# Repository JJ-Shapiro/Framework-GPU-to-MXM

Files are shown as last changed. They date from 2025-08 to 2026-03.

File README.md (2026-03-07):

# Framework-GPU-to-MXM
A project to make the first MXM module for the Framework 16.
*Info*
The Framework 16's Expansion bay can't support the size of an MXM module by default, (at least not a type-B module which is bigger than a type a module), but it *can* support it if the back of the GPU expansion slot is pulled out further 

Screenshot 2026-01-25 at 11 29 57 pm



3D_PCB6_2025-08-20



*Disclaimer*
I am not the legal owner of the datasheet describing the footprint of an MXM connector. It is in this repository strictly as a helpful reference for anyone who might desire to use or cross reference it. I will of course remove it at the request of the author.

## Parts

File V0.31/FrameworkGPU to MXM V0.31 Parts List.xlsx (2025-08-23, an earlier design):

No. | Quantity | Comment | Designator | Footprint | Value | Manufacturer Part | Manufacturer | Supplier Part | Supplier | Input Voltage | Datasheet | Current Rating - Power (Max)
1 | 16 | 220nF | C1,C2,C3,C4,C5,C6,C7,C8,C9,C10,C11,C12,C13,C14,C15,C16 | C0402 | 220nF
2 | 11 | 100nF | C17,C18,C19,C20,C21,C22,C23,C24,C25,C26,C27 | C0603 | 100nF
3 | 3 | 0.1uF | C73,C74,C75 | C0402
4 | 2 | SFW4R-2STE1LF | FPC1,FPC2 | CONN-SMD_4P-P1.00_L5.5-W9.8 |  | SFW4R-2STE1LF | Amphenol | C464570 | LCSC |  | https://atta.szlcsc.com/upload/public/pdf/source/20191127/C464570_B2B1FDB2254A36EE71D2D8D3CD76F95C.pdf
5 | 1 | MXM3.0 | J1 | CONN-SMD_314P-P0.50_10151114-001TLF | MXM3.0
6 | 1 | 100M | L1 | L0603 | 100M
7 | 3 | 0/NC | R43,R45,R47 | R0402 | 0/NC
8 | 9 | 0 | R44,R46,R48,R53,R54,R55,R56,R59,R60 | R0402 | 0
9 | 2 | 100K ±1% | R49,R52 | R0402 | 100K ±1%
10 | 2 | 4.7K ±1% | R50,R51 | R0402 | 4.7K ±1%
11 | 2 | 330k ±1% | R57,R58 | R0402 | 330k ±1%
12 | 29 | Test-Point | TP1,TP2,TP3,TP4,TP5,TP6,TP7,TP8,TP9,TP10,TP11,TP12,TP13,TP14,TP15,TP16,TP17,TP18,TP19,TP20,TP21,TP22,TP23,TP24,TP25,TP26,TP27,TP28,TP29 | Test-Point-0.5mm
13 | 1 | FXBeam | U2 | FW_FXBEAM_FULL
14 | 1 | BR24G32FVT-3GE2 | U54 | TSSOP-8_L4.4-W3.0-P0.65-LS6.4-BL |  | BR24G32FVT-3GE2 | ROHM(罗姆) | C2061284 | LCSC |  | https://atta.szlcsc.com/upload/public/pdf/source/20211207/04F260C112D11C6089B8D1D4B01C0AA6.pdf

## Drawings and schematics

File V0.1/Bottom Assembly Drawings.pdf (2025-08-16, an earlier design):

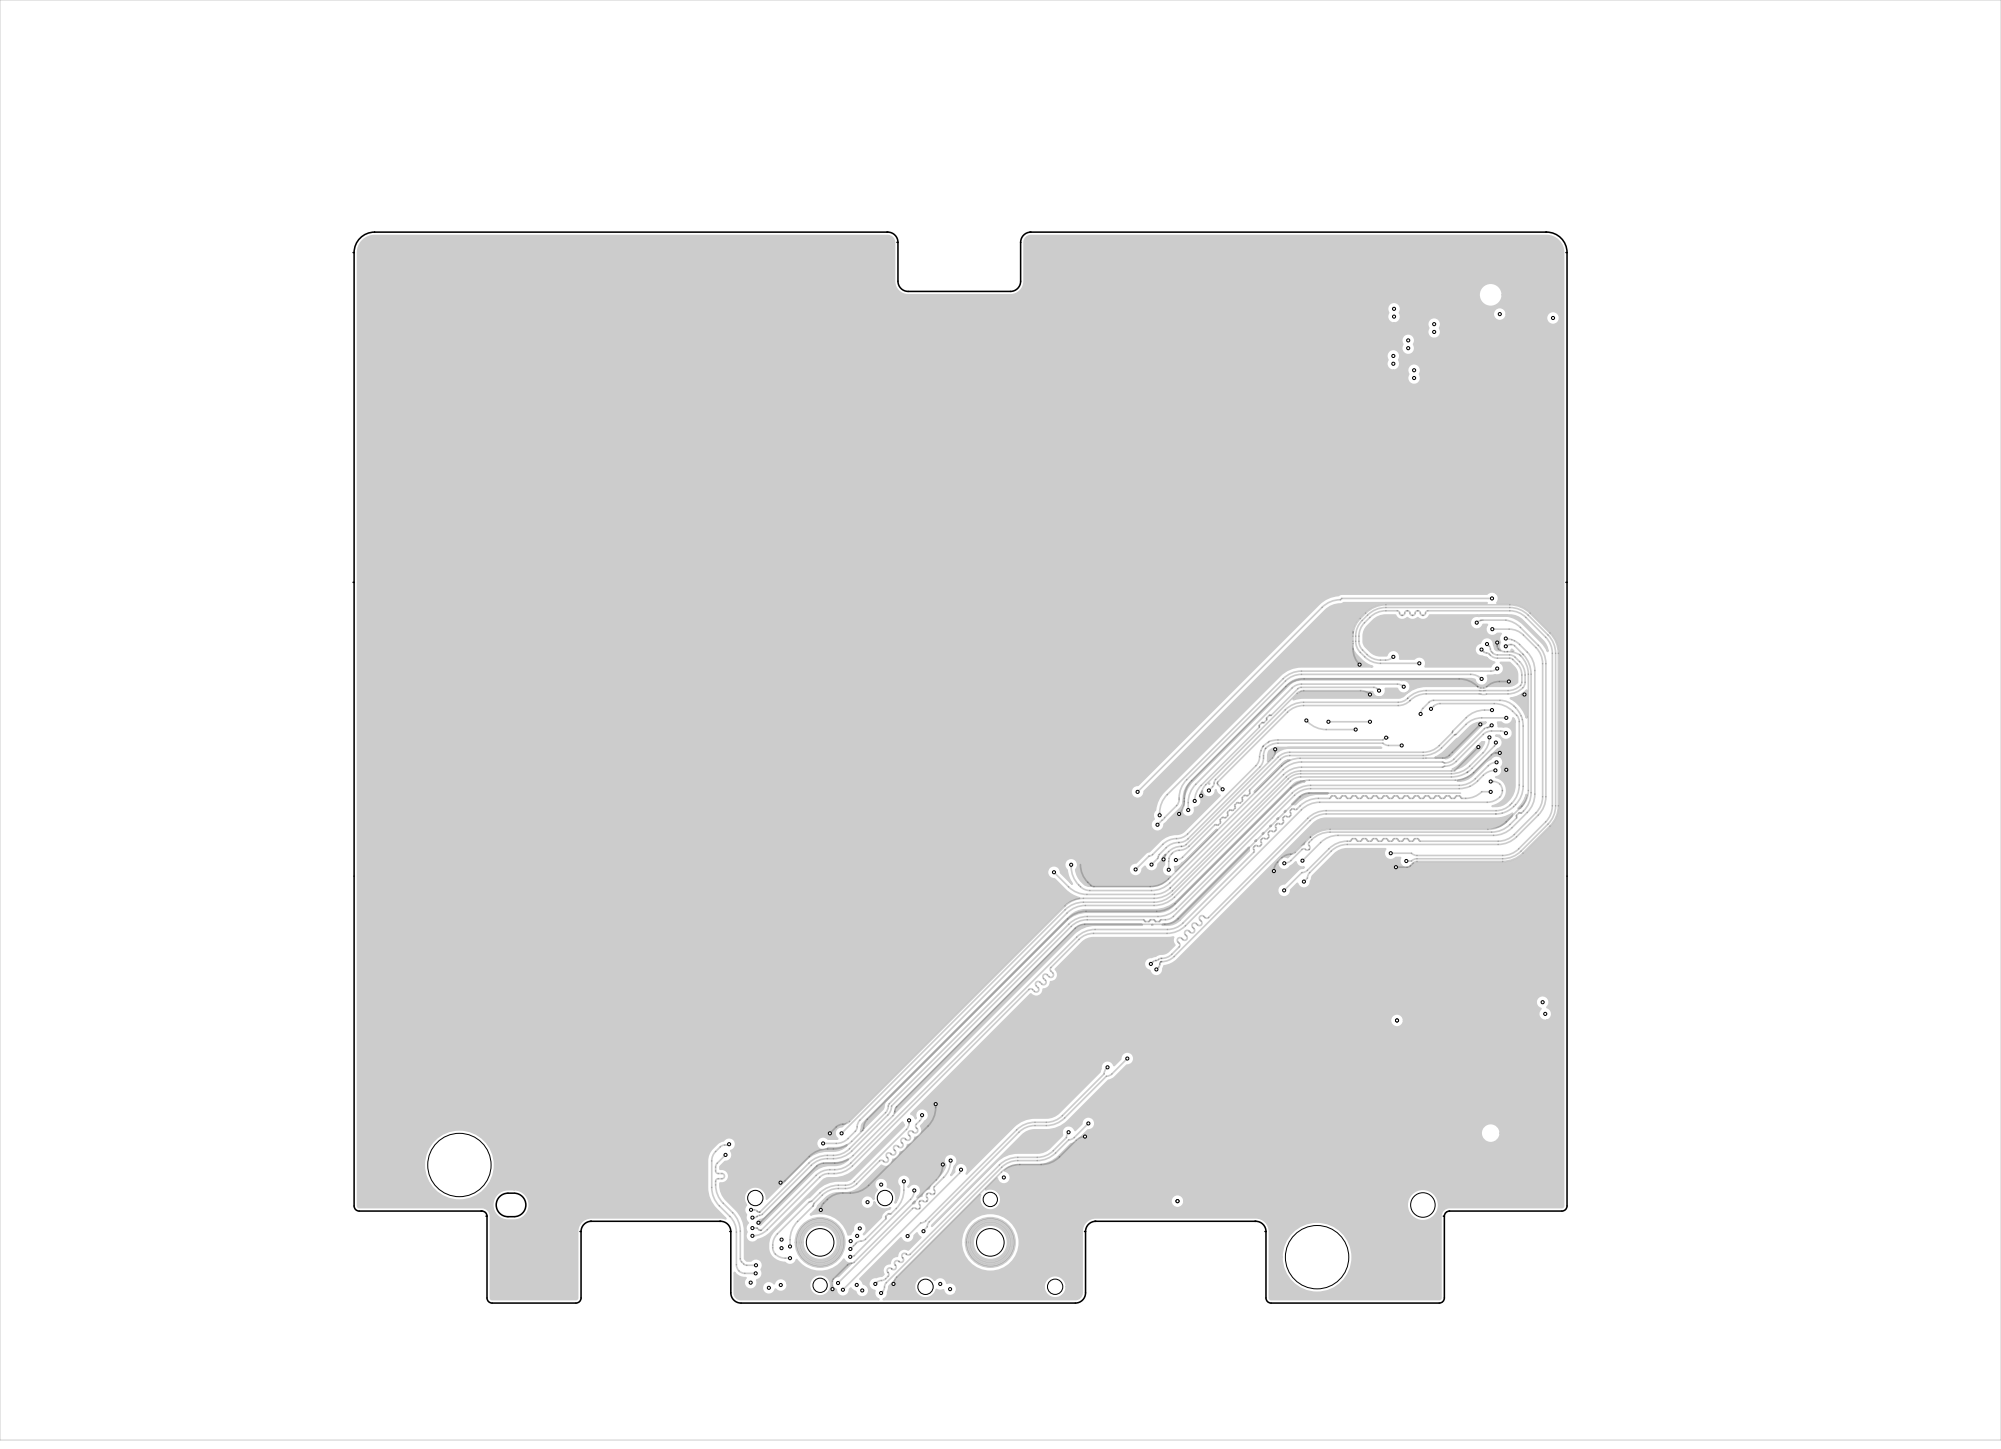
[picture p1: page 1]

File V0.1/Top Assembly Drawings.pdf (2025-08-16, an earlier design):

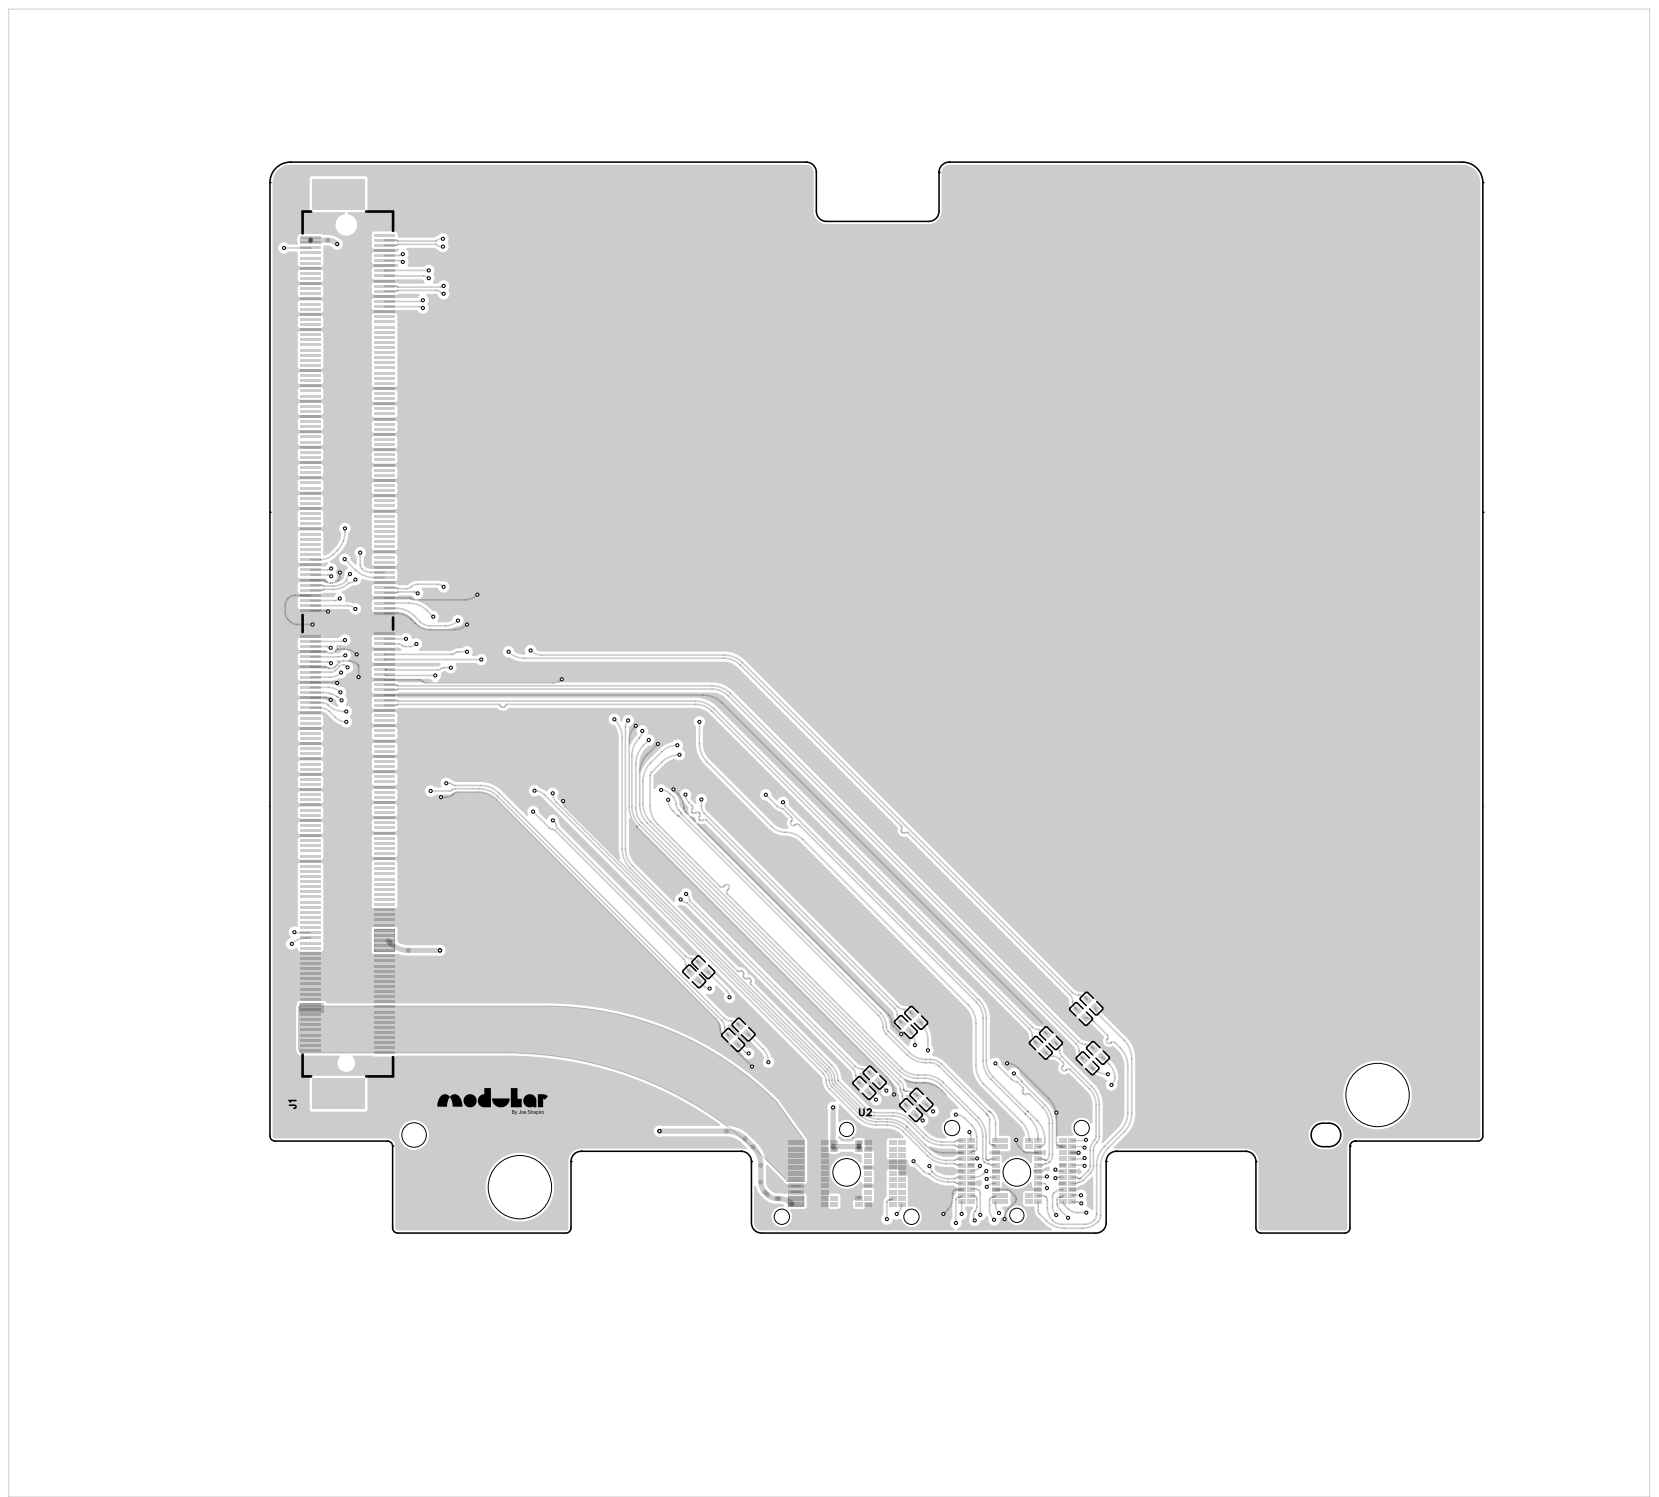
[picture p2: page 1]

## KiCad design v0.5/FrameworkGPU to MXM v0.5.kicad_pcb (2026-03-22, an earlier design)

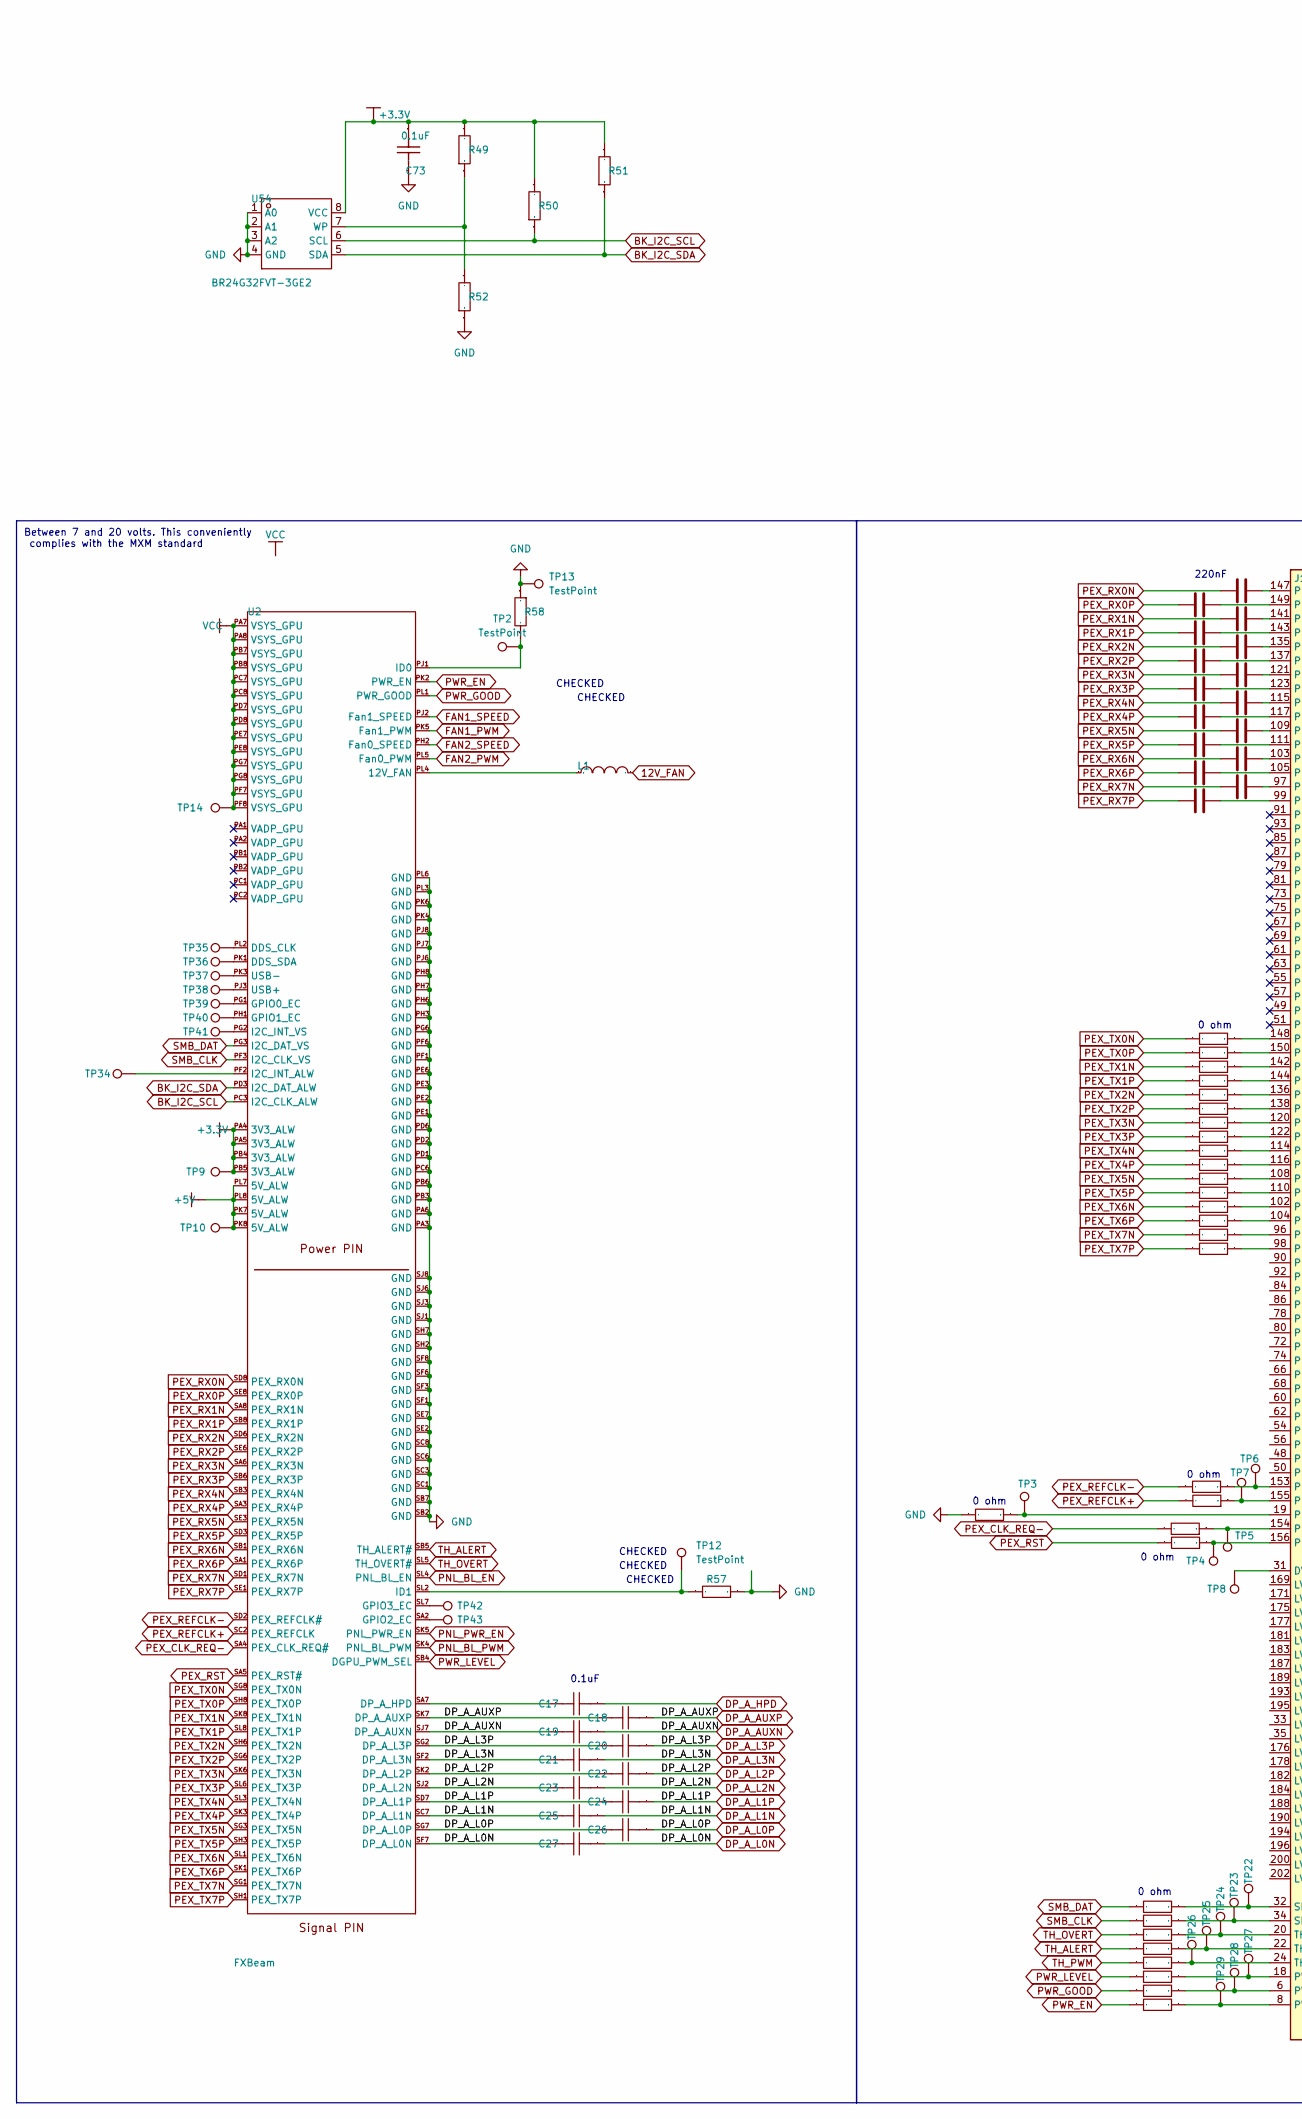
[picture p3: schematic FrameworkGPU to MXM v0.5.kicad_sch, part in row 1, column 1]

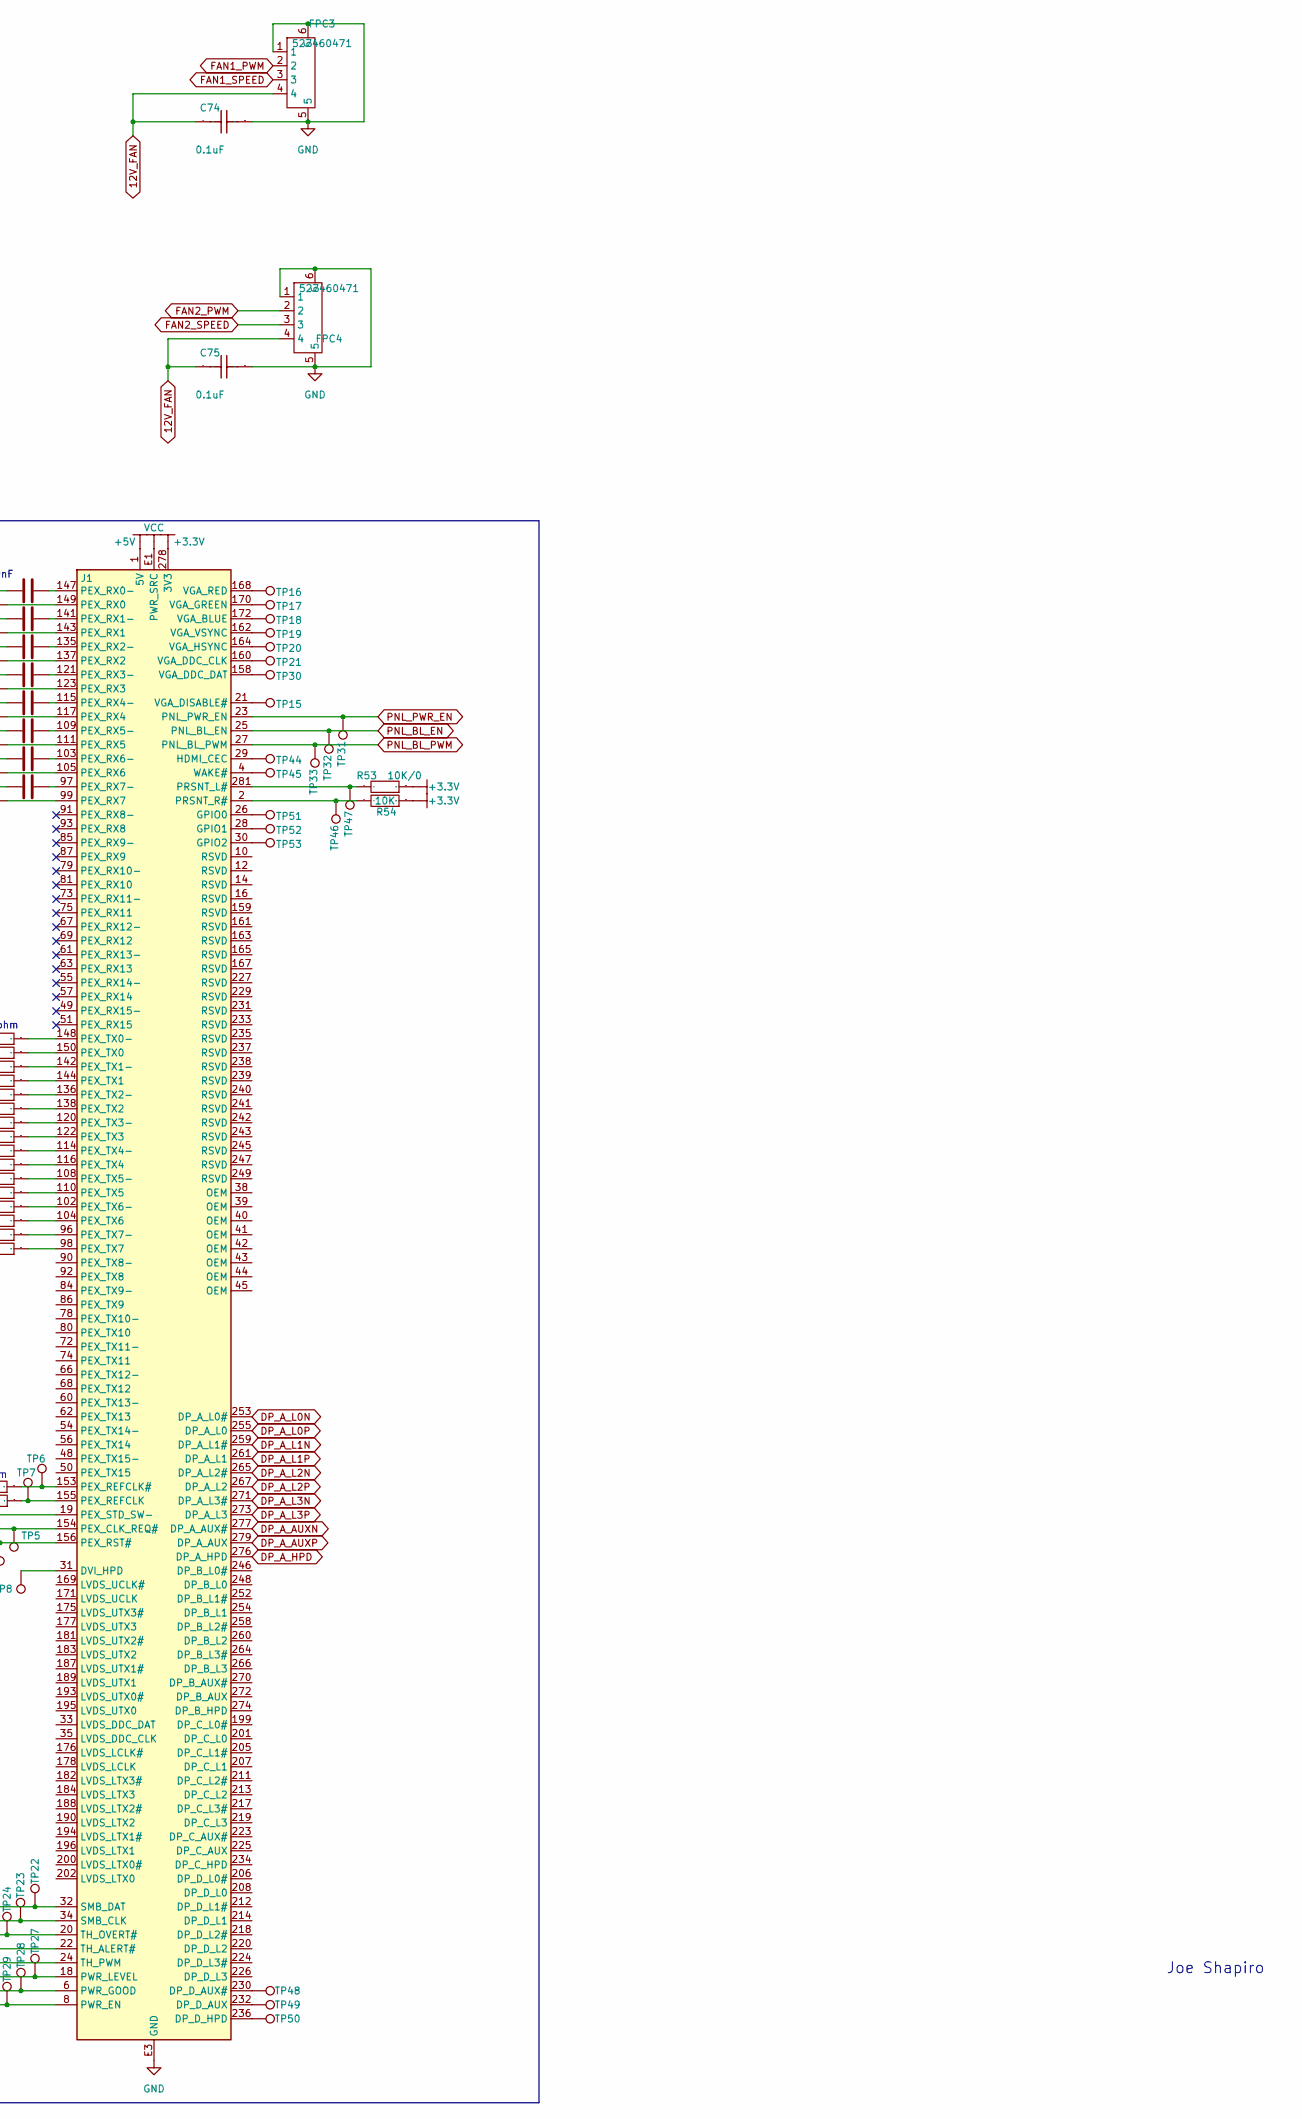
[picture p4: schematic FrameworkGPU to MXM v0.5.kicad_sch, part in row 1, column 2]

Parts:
C1, C2, C3, C4, C5, C6, C7, C8, C9, C10, C11, C12, C13, C14, C15, C16: 220nF; 0603
C17, C18, C19, C20, C21, C22, C23, C24, C25, C26, C27: 100nF; 0603
C73, C74, C75: 0.1uF; 0603
FPC3, FPC4: 527460471; FPC-SMD_4P-P0.50_MOLEX_0527460471; Manufacturer Part 527460471; LCSC Part Name 527460471
J1: MXM3.0; FOXCONN_AS0B826-S55B-7H
L1: 10uH; 0603
R17, R18, R19, R20, R21, R22, R23, R24, R25, R26, R27, R28, R29, R30, R31, R32, R33, R34, R35, R36, R37, R55, R56, R59, R60, R61, R62, R63, R64: 0; 0603
R49, R54: 10K; 0603
R50, R51: 4.7K; 0603
R52: 100K; 0603
R53: 10K/0; 0603
R57, R58: 330K; 0603
TP2, TP3, TP4, TP5, TP6, TP7, TP8, TP9, TP10, TP12, TP13, TP14, TP15, TP16, TP17, TP18, TP19, TP20, TP21, TP22, TP23, TP24, TP25, TP26, TP27, TP28, TP29, TP30, TP31, TP32, TP33, TP34, TP35, TP36, TP37, TP38, TP39, TP40, TP41, TP42, TP43, TP44, TP45, TP46, TP47, TP48, TP49, TP50, TP51, TP52, TP53: TestPoint; TestPoint_Pad_D3.0mm
U2: FXBeam; Expansion Bay FXBeam
U54: BR24G32FVT-3GE2; SOP65P640X120-8N; Manufacturer Part BR24G32FVT-3GE2; LCSC Part Name BR24G32FVT-3GE2

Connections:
+3.3V: C73.1, J1.278 (3V3), J1.280 (3V3), R49.2, R50.2, R51.2, R53.1, R54.1, TP9.1, U2.PA4 (3V3_ALW), U2.PA5 (3V3_ALW), U2.PB4 (3V3_ALW), U2.PB5 (3V3_ALW), U54.8 (VCC)
+5V: J1.1 (5V), J1.3 (5V), J1.5 (5V), J1.7 (5V), J1.9 (5V), TP10.1, U2.PK7 (5V_ALW), U2.PK8 (5V_ALW), U2.PL7 (5V_ALW), U2.PL8 (5V_ALW)
BK_I2C_SCL: R50.1, U2.PC3 (I2C_CLK_ALW), U54.6 (SCL)
BK_I2C_SDA: R51.1, U2.PD3 (I2C_DAT_ALW), U54.5 (SDA)
DP_A_AUXN: C19.1, C19.2, J1.277 (DP_A_AUX#), U2.SJ7 (DP_A_AUXN)
DP_A_AUXP: C18.1, C18.2, J1.279 (DP_A_AUX), U2.SK7 (DP_A_AUXP)
DP_A_HPD: C17.1, J1.276 (DP_A_HPD)
DP_A_L0N: C27.1, C27.2, J1.253 (DP_A_L0#), U2.SF7 (DP_A_L0N)
DP_A_L0P: C26.1, C26.2, J1.255 (DP_A_L0), U2.SG7 (DP_A_L0P)
DP_A_L1N: C25.1, C25.2, J1.259 (DP_A_L1#), U2.SC7 (DP_A_L1N)
DP_A_L1P: C24.1, C24.2, J1.261 (DP_A_L1), U2.SD7 (DP_A_L1P)
DP_A_L2N: C23.1, C23.2, J1.265 (DP_A_L2#), U2.SJ2 (DP_A_L2N)
DP_A_L2P: C22.1, C22.2, J1.267 (DP_A_L2), U2.SK2 (DP_A_L2P)
DP_A_L3N: C21.1, C21.2, J1.271 (DP_A_L3#), U2.SF2 (DP_A_L3N)
DP_A_L3P: C20.1, C20.2, J1.273 (DP_A_L3), U2.SG2 (DP_A_L3P)
FAN1_PWM: FPC3.2, U2.PK5 (Fan1_PWM)
FAN1_SPEED: FPC3.3, U2.PJ2 (Fan1_SPEED)
FAN2_PWM: FPC4.2, U2.PL5 (Fan0_PWM)
FAN2_SPEED: FPC4.3, U2.PH2 (Fan0_SPEED)
GND: C73.2, C74.1, C75.1, FPC3.1, FPC3.5, FPC3.6, FPC4.1, FPC4.5, FPC4.6, J1.11 (GND), J1.13 (GND), J1.15 (GND), J1.17 (GND), J1.36 (GND), J1.37 (GND), J1.46 (GND), J1.47 (GND), J1.52 (GND), J1.53 (GND), J1.58 (GND), J1.59 (GND), J1.64 (GND), J1.65 (GND), J1.70 (GND), J1.71 (GND), J1.76 (GND), J1.77 (GND), J1.82 (GND), J1.83 (GND), J1.88 (GND), J1.89 (GND), J1.94 (GND), J1.95 (GND), J1.100 (GND), J1.101 (GND), J1.106 (GND), J1.107 (GND), J1.112 (GND), J1.113 (GND), J1.118 (GND), J1.119 (GND), J1.124 (GND), J1.125 (GND), J1.133 (GND), J1.134 (GND), J1.139 (GND), J1.140 (GND), J1.145 (GND), J1.146 (GND), J1.151 (GND), J1.152 (GND), J1.157 (GND), J1.166 (GND), J1.173 (GND), J1.174 (GND), J1.179 (GND), J1.180 (GND), J1.185 (GND), J1.186 (GND), J1.191 (GND), J1.192 (GND), J1.197 (GND), J1.198 (GND), J1.203 (GND), J1.204 (GND), J1.209 (GND), J1.210 (GND), J1.215 (GND), J1.216 (GND), J1.221 (GND), J1.222 (GND), J1.228 (GND), J1.244 (GND), J1.250 (GND), J1.251 (GND), J1.256 (GND), J1.257 (GND), J1.262 (GND), J1.263 (GND), J1.268 (GND), J1.269 (GND), J1.275 (GND), J1.E3 (GND), J1.E4 (GND), R33.2, R52.1, R57.1, R58.1, TP13.1, U2.PA3 (GND), U2.PA6 (GND), U2.PB3 (GND), U2.PB6 (GND), U2.PC6 (GND), U2.PD1 (GND), U2.PD2 (GND), U2.PD6 (GND), U2.PE1 (GND), U2.PE2 (GND), U2.PE3 (GND), U2.PE6 (GND), U2.PF1 (GND), U2.PF6 (GND), U2.PG6 (GND), U2.PH3 (GND), U2.PH6 (GND), U2.PH7 (GND), U2.PH8 (GND), U2.PJ6 (GND), U2.PJ7 (GND), U2.PJ8 (GND), U2.PK4 (GND), U2.PK6 (GND), U2.PL3 (GND), U2.PL6 (GND), U2.SB2 (GND), U2.SB7 (GND), U2.SC1 (GND), U2.SC3 (GND), U2.SC6 (GND), U2.SC8 (GND), U2.SE2 (GND), U2.SE7 (GND), U2.SF1 (GND), U2.SF3 (GND), U2.SF6 (GND), U2.SF8 (GND), U2.SH2 (GND), U2.SH7 (GND), U2.SJ1 (GND), U2.SJ3 (GND), U2.SJ6 (GND), U2.SJ8 (GND), U54.1 (A0), U54.2 (A1), U54.3 (A2), U54.4 (GND)
unnamed: C74.2, C75.2, FPC3.4, FPC4.4, L1.2
unnamed: J1.230 (DP_D_AUX#), TP48.1
unnamed: J1.232 (DP_D_AUX), TP49.1
unnamed: J1.236 (DP_D_HPD), TP50.1
unnamed: J1.31 (DVI_HPD), TP8.1
unnamed: J1.26 (GPIO0), TP51.1
unnamed: J1.28 (GPIO1), TP52.1
unnamed: J1.30 (GPIO2), TP53.1
unnamed: J1.29 (HDMI_CEC), TP44.1
unnamed: J1.154 (PEX_CLK_REQ#), R35.1, TP5.1
unnamed: J1.153 (PEX_REFCLK#), R36.1, TP6.1
unnamed: J1.155 (PEX_REFCLK), R37.1, TP7.1
unnamed: J1.156 (PEX_RST#), R34.1, TP4.1
unnamed: C1.1, J1.149 (PEX_RX0)
unnamed: C9.1, J1.147 (PEX_RX0-)
unnamed: C2.1, J1.143 (PEX_RX1)
unnamed: C10.1, J1.141 (PEX_RX1-)
unnamed: C3.1, J1.137 (PEX_RX2)
unnamed: C11.1, J1.135 (PEX_RX2-)
unnamed: C4.1, J1.123 (PEX_RX3)
unnamed: C12.1, J1.121 (PEX_RX3-)
unnamed: C5.1, J1.117 (PEX_RX4)
unnamed: C13.1, J1.115 (PEX_RX4-)
unnamed: C6.1, J1.111 (PEX_RX5)
unnamed: C14.1, J1.109 (PEX_RX5-)
unnamed: C7.1, J1.105 (PEX_RX6)
unnamed: C15.1, J1.103 (PEX_RX6-)
unnamed: C8.1, J1.99 (PEX_RX7)
unnamed: C16.1, J1.97 (PEX_RX7-)
unnamed: J1.19 (PEX_STD_SW-), R33.1, TP3.1
unnamed: J1.150 (PEX_TX0), R18.1
unnamed: J1.148 (PEX_TX0-), R17.1
unnamed: J1.144 (PEX_TX1), R20.1
unnamed: J1.142 (PEX_TX1-), R19.1
unnamed: J1.138 (PEX_TX2), R22.1
unnamed: J1.136 (PEX_TX2-), R21.1
unnamed: J1.122 (PEX_TX3), R24.1
unnamed: J1.120 (PEX_TX3-), R23.1
unnamed: J1.116 (PEX_TX4), R26.1
unnamed: J1.114 (PEX_TX4-), R25.1
unnamed: J1.110 (PEX_TX5), R28.1
unnamed: J1.108 (PEX_TX5-), R27.1
unnamed: J1.104 (PEX_TX6), R30.1
unnamed: J1.102 (PEX_TX6-), R29.1
unnamed: J1.98 (PEX_TX7), R32.1
unnamed: J1.96 (PEX_TX7-), R31.1
unnamed: J1.281 (PRSNT_L#), R53.2, TP47.1
unnamed: J1.2 (PRSNT_R#), R54.2, TP46.1
unnamed: J1.8 (PWR_EN), R64.1, TP29.1
unnamed: J1.6 (PWR_GOOD), R63.1, TP28.1
unnamed: J1.18 (PWR_LEVEL), R62.1, TP27.1
unnamed: J1.34 (SMB_CLK), R56.1, TP23.1
unnamed: J1.32 (SMB_DAT), R55.1, TP22.1
unnamed: J1.22 (TH_ALERT#), R60.1, TP25.1
unnamed: J1.20 (TH_OVERT#), R59.1, TP24.1
unnamed: J1.24 (TH_PWM), R61.1, TP26.1
unnamed: J1.172 (VGA_BLUE), TP18.1
unnamed: J1.160 (VGA_DDC_CLK), TP21.1
unnamed: J1.158 (VGA_DDC_DAT), TP30.1
unnamed: J1.21 (VGA_DISABLE#), TP15.1
unnamed: J1.170 (VGA_GREEN), TP17.1
unnamed: J1.164 (VGA_HSYNC), TP20.1
unnamed: J1.168 (VGA_RED), TP16.1
unnamed: J1.162 (VGA_VSYNC), TP19.1
unnamed: J1.4 (WAKE#), TP45.1
unnamed: L1.1, U2.PL4 (12V_FAN)
unnamed: TP35.1, U2.PL2 (DDS_CLK)
unnamed: TP36.1, U2.PK1 (DDS_SDA)
unnamed: C17.2, U2.SA7 (DP_A_HPD)
unnamed: TP39.1, U2.PG1 (GPIO0_EC)
unnamed: TP40.1, U2.PH1 (GPIO1_EC)
unnamed: TP43.1, U2.SA2 (GPIO2_EC)
unnamed: TP42.1, U2.SL7 (GPIO3_EC)
unnamed: TP34.1, U2.PF2 (I2C_INT_ALW)
unnamed: TP41.1, U2.PG2 (I2C_INT_VS)
unnamed: R58.2, TP2.1, U2.PJ1 (ID0)
unnamed: R57.2, TP12.1, U2.SL2 (ID1)
unnamed: TP38.1, U2.PJ3 (USB+)
unnamed: TP37.1, U2.PK3 (USB-)
unnamed: R49.1, R52.2, U54.7 (WP)
PEX_CLK_REQ-: R35.2, U2.SA4 (PEX_CLK_REQ#)
PEX_REFCLK+: R37.2, U2.SC2 (PEX_REFCLK)
PEX_REFCLK-: R36.2, U2.SD2 (PEX_REFCLK#)
PEX_RST: R34.2, U2.SA5 (PEX_RST#)
PEX_RX0N: C9.2, U2.SD8 (PEX_RX0N)
PEX_RX0P: C1.2, U2.SE8 (PEX_RX0P)
PEX_RX1N: C10.2, U2.SA8 (PEX_RX1N)
PEX_RX1P: C2.2, U2.SB8 (PEX_RX1P)
PEX_RX2N: C11.2, U2.SD6 (PEX_RX2N)
PEX_RX2P: C3.2, U2.SE6 (PEX_RX2P)
PEX_RX3N: C12.2, U2.SA6 (PEX_RX3N)
PEX_RX3P: C4.2, U2.SB6 (PEX_RX3P)
PEX_RX4N: C13.2, U2.SB3 (PEX_RX4N)
PEX_RX4P: C5.2, U2.SA3 (PEX_RX4P)
PEX_RX5N: C14.2, U2.SE3 (PEX_RX5N)
PEX_RX5P: C6.2, U2.SD3 (PEX_RX5P)
PEX_RX6N: C15.2, U2.SB1 (PEX_RX6N)
PEX_RX6P: C7.2, U2.SA1 (PEX_RX6P)
PEX_RX7N: C16.2, U2.SD1 (PEX_RX7N)
PEX_RX7P: C8.2, U2.SE1 (PEX_RX7P)
PEX_TX0N: R17.2, U2.SG8 (PEX_TX0N)
PEX_TX0P: R18.2, U2.SH8 (PEX_TX0P)
PEX_TX1N: R19.2, U2.SK8 (PEX_TX1N)
PEX_TX1P: R20.2, U2.SL8 (PEX_TX1P)
PEX_TX2N: R21.2, U2.SH6 (PEX_TX2N)
PEX_TX2P: R22.2, U2.SG6 (PEX_TX2P)
PEX_TX3N: R23.2, U2.SK6 (PEX_TX3N)
PEX_TX3P: R24.2, U2.SL6 (PEX_TX3P)
PEX_TX4N: R25.2, U2.SL3 (PEX_TX4N)
PEX_TX4P: R26.2, U2.SK3 (PEX_TX4P)
PEX_TX5N: R27.2, U2.SG3 (PEX_TX5N)
PEX_TX5P: R28.2, U2.SH3 (PEX_TX5P)
PEX_TX6N: R29.2, U2.SL1 (PEX_TX6N)
PEX_TX6P: R30.2, U2.SK1 (PEX_TX6P)
PEX_TX7N: R31.2, U2.SG1 (PEX_TX7N)
PEX_TX7P: R32.2, U2.SH1 (PEX_TX7P)
PNL_BL_EN: J1.25 (PNL_BL_EN), TP32.1, U2.SL4 (PNL_BL_EN)
PNL_BL_PWM: J1.27 (PNL_BL_PWM), TP33.1, U2.SK4 (PNL_BL_PWM)
PNL_PWR_EN: J1.23 (PNL_PWR_EN), TP31.1, U2.SK5 (PNL_PWR_EN)
PWR_EN: R64.2, U2.PK2 (PWR_EN)
PWR_GOOD: R63.2, U2.PL1 (PWR_GOOD)
PWR_LEVEL: R62.2, U2.SB4 (DGPU_PWM_SEL)
SMB_CLK: R56.2, U2.PF3 (I2C_CLK_VS)
SMB_DAT: R55.2, U2.PG3 (I2C_DAT_VS)
TH_ALERT: R60.2, U2.SB5 (TH_ALERT#)
TH_OVERT: R59.2, U2.SL5 (TH_OVERT#)
TH_PWM: R61.2
VCC: J1.E1 (PWR_SRC), J1.E2 (PWR_SRC), TP14.1, U2.PA7 (VSYS_GPU), U2.PA8 (VSYS_GPU), U2.PB7 (VSYS_GPU), U2.PB8 (VSYS_GPU), U2.PC7 (VSYS_GPU), U2.PC8 (VSYS_GPU), U2.PD7 (VSYS_GPU), U2.PD8 (VSYS_GPU), U2.PE7 (VSYS_GPU), U2.PE8 (VSYS_GPU), U2.PF7 (VSYS_GPU), U2.PF8 (VSYS_GPU), U2.PG7 (VSYS_GPU), U2.PG8 (VSYS_GPU)

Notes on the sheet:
0 ohm
CHECKED
0.1uF
Joe Shapiro
Between 7 and 20 volts. This conveniently complies with the MXM standard
220nF

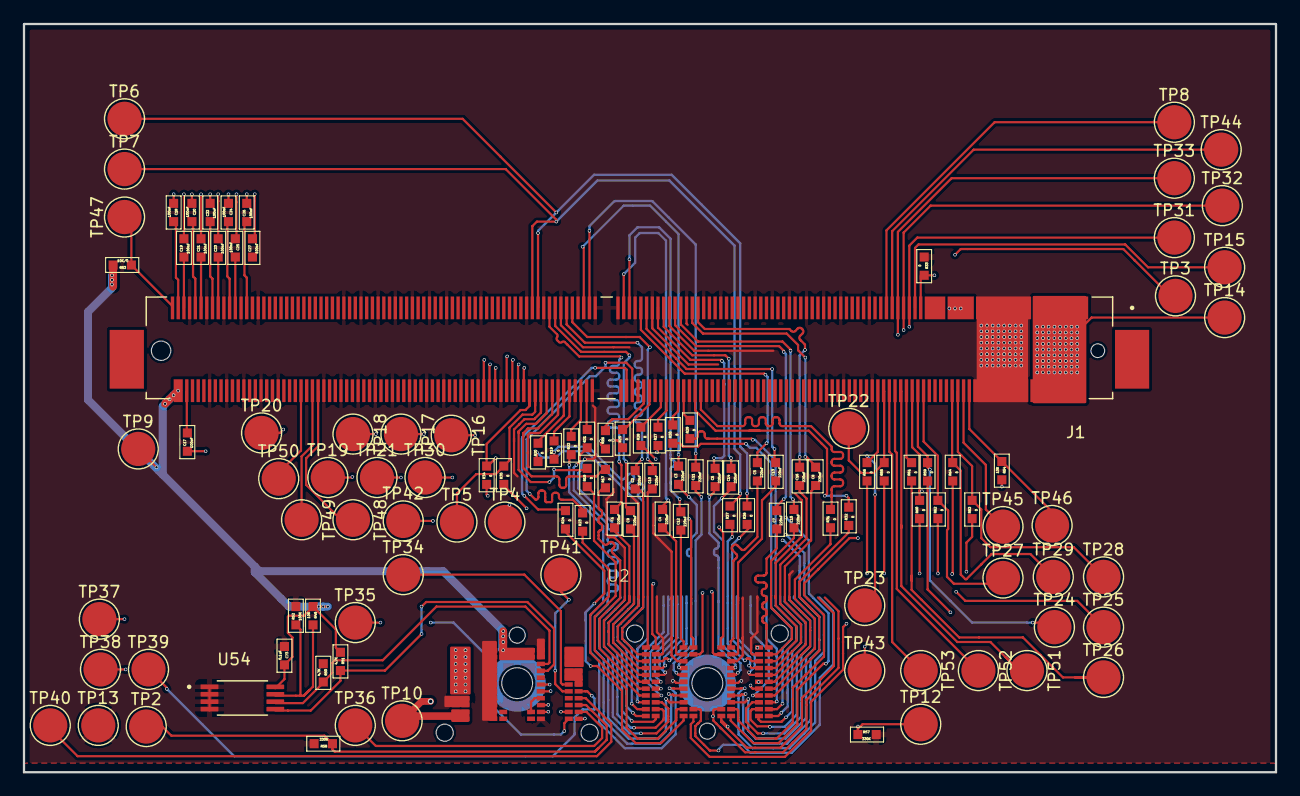
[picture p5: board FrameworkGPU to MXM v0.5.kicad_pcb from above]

Board: 6 copper layers, 109.6 x 65.5 mm, 119 parts (0 on the bottom side), 141 nets.

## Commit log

2025-08-19 Rename FrameworkGPU to MXM.epro to V0.1/FrameworkGPU to MXM.epro
2025-08-19 Rename Bottom Assembly Drawings.pdf to Bottom Assembly Drawings.pdf
2025-08-19 Rename Drill Drawing.pdf to Drill Drawing.pdf
2025-08-19 Rename Top Assembly Drawings.pdf to Top Assembly Drawings.pdf
2025-08-19 Rename FrameworkGPU to MXM V0.2_2025-08-19.epro to V0.2/FrameworkGPU to MXM V0.2_2025-08-19.epro
2025-08-20 Rename FrameworkGPU to MXM V0.3.epro to V0.3/FrameworkGPU to MXM V0.3.epro
2025-08-21 Rename FrameworkGPU to MXM V0.4.epro to V0.4/FrameworkGPU to MXM V0.4.epro
2025-08-23 Rename FrameworkGPU to MXM V0.31.epro to V0.31/FrameworkGPU to MXM V0.31.epro
2025-09-18 Rename FrameworkGPU to MXM V3.2.epro to V3.2/FrameworkGPU to MXM V3.2.epro
2025-09-22 V3.3 Added
    Fixed fan headers and completed length matching
2025-09-22 Rename FrameworkGPU to MXM V3.3.epro to V3.3/FrameworkGPU to MXM V3.3.epro
2025-09-28 Rename MXM Schematic Footprint.pdf to Datasheets/MXM Schematic Footprint.pdf
2025-11-28 Rename FrameworkGPU to MXM v0.34.epro to v0.34/FrameworkGPU to MXM v0.34.epro
2025-11-28 Rename FrameworkGPU to MXM V3.3.epro to FrameworkGPU to MXM V3.3.epro
2025-11-28 Rename V3.2/FrameworkGPU to MXM V3.2.epro to V0.32FrameworkGPU to MXM V3.2.epro
2025-11-28 Rename V0.32FrameworkGPU to MXM V3.2.epro to v0.32/FrameworkGPU to MXM V3.2.epro
2026-03-07 added v0.5
    [FrameworkGPU to MXM v0.5-B_Cu.gbr, FrameworkGPU to MXM v0.5-B_Mask.gbr, FrameworkGPU to MXM v0.5-B_Paste.gbr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]
2026-03-07 Diff routed
    [FrameworkGPU to MXM v0.5.kicad_pcb, FrameworkGPU to MXM v0.5.kicad_sch]
2026-03-22 committing final version sent off for manufacturing
    [FrameworkGPU to MXM v0.5-B_Cu.gbl, FrameworkGPU to MXM v0.5-B_Cu.gbr, FrameworkGPU to MXM v0.5-B_Mask.gbr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]
